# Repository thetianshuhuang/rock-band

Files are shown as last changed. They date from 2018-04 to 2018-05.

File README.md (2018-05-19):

# EE319K Final Project: Rock Band
Tianshu Huang and Quinn Buoy

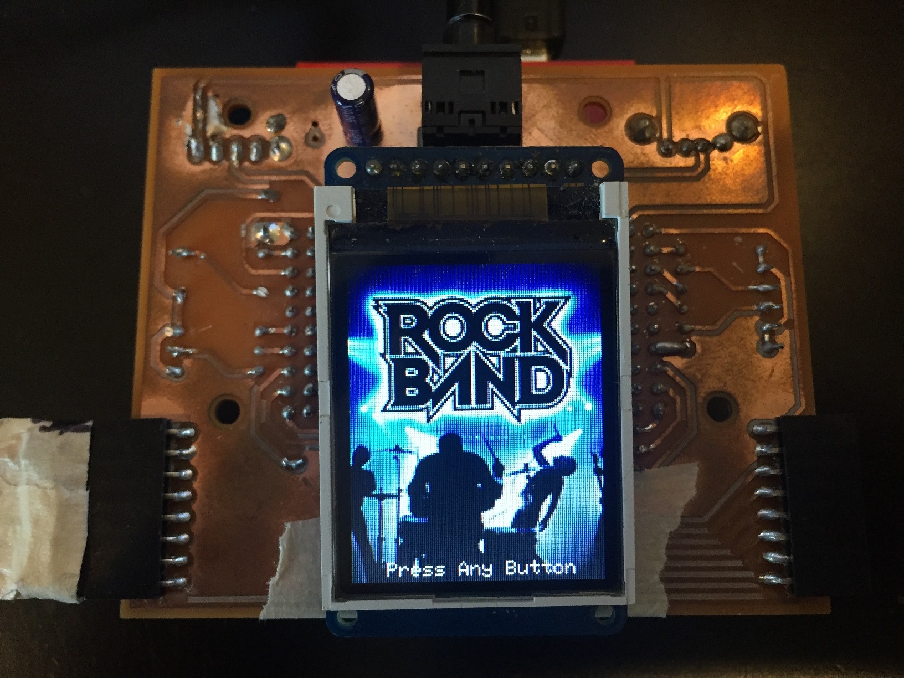
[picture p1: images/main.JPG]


## Game Overview
### Features
- 44.1kHz, 8 bit audio
- Audio and tracks via SD read
- inifinitely many songs supported, just by expanding the menu
- Full resolution (128x160) splash screens

### Dependencies
- tm4c123gh6p.h (tm4c hardware register definition file)
- PLL.h (TM4C PLL; used for 80mHz clock)
- FATFS; ST7735.h and diskio.h from Valvanoware (modified)

### Libraries and Modules
- Network: token network implementation, modified from Serial Token Ring
- Audio: SD read and DAC out; 8 bit x 44.1kHz (44.1kBps bitrate)
- Controller: Four digital and one analog, and derivative routines for the strummer
- Game: Core game control
- Display: SD drivers and display routines
- Menu: Generalized menu library using function pointers
- Graphics: Display routines for the guitar, splash screen, and misc utilities

### File Types
- Packed Image (.pi): packed 5-6-5 GBR 16-bit image, uncompressed, scanning starting from bottom left, across, then up
- Byte wave file (.bw): raw audio file, bit-depth of 8, 44.1kHz
- Rock Band Track (.rb): 16-bit array.
```
| R | Y | B | G | Reserved | Reserved | -- (10) Tick -- |
```
	- R, Y, B, G indicates whether each drum should be hit (1) at that note
or not (0).
	- Tick indicates the number of updates (441 updates/s or 100 audio ticks/update)
before the next note.

## Gameplay
Navigate the menus using the four buttons or by hitting the drums.

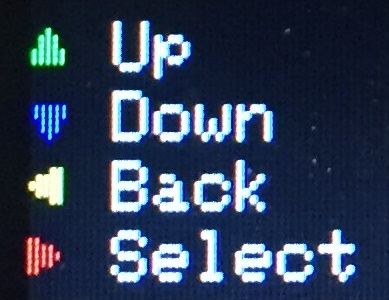
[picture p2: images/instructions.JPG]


At first, the Menu screen will have a black background. Navigate to 'select instrument', and choose the desired instrument. Then, the background will change to match the chosen instrument. Then, select 'Enable Full Mode' to disable the 2:30 time limit on song duration if desired.

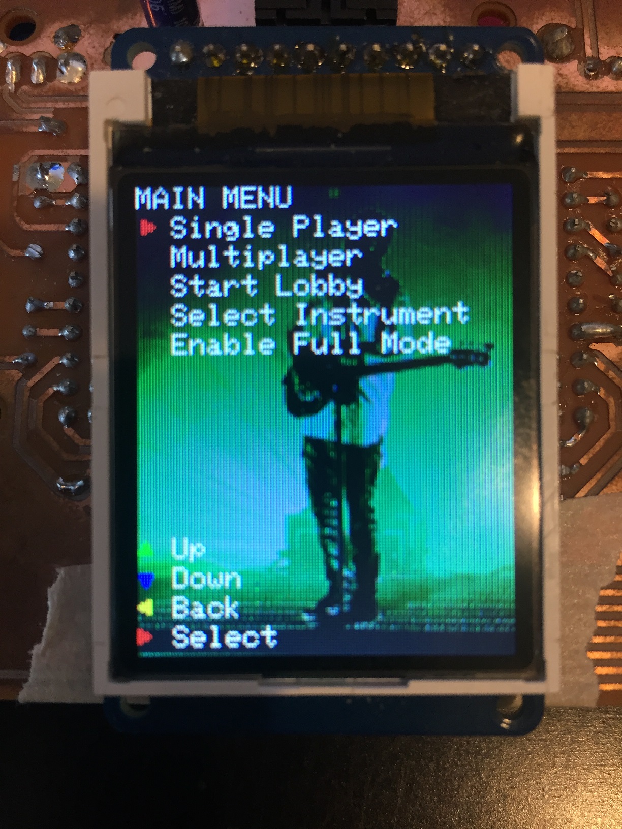
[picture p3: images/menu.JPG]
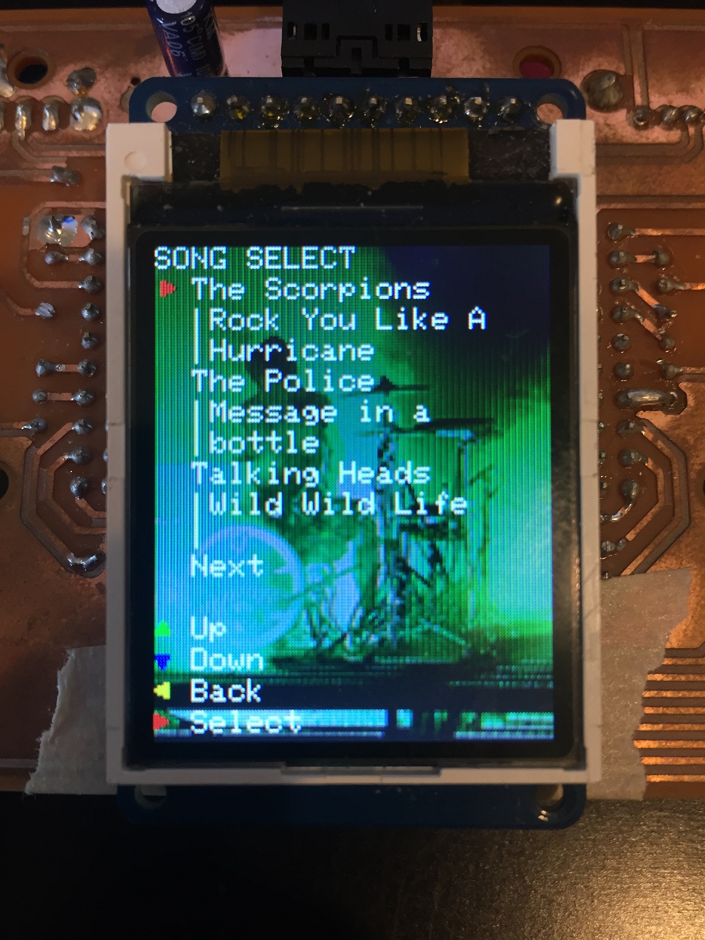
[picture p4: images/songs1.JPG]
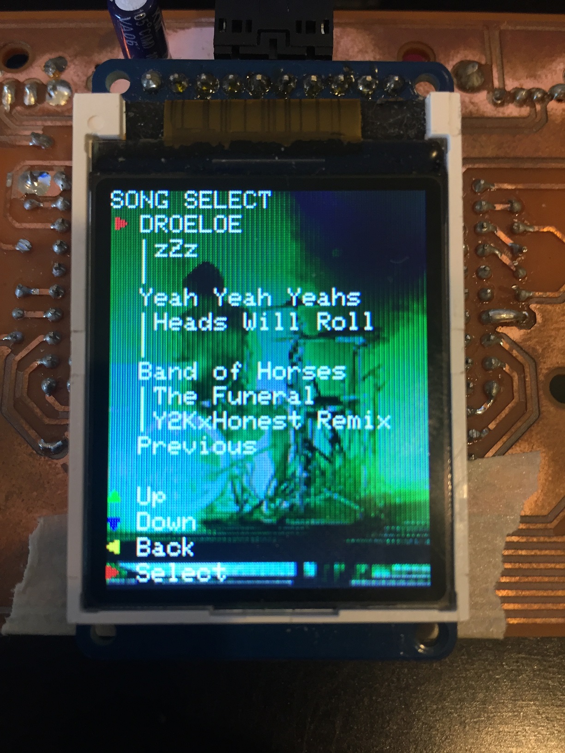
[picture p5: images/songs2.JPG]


All but one device should choose 'Join Lobby'. These devices will wait for the main ('Lobby Leader') device to choose a song, and join in.

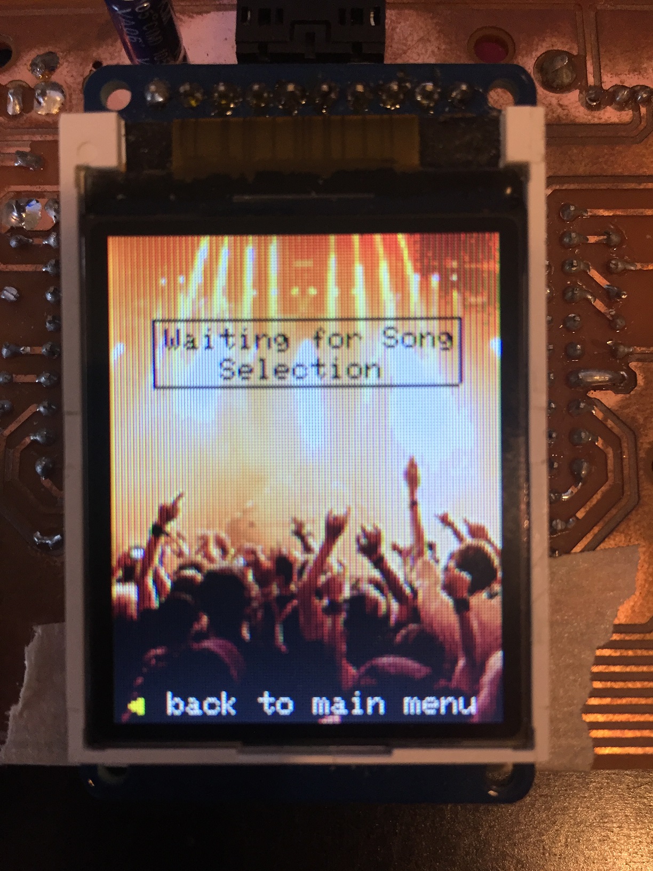
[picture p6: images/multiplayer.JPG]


All devices on the multiplayer "Waiting for Song Selection" screen will join the main device once a song is selected.
After a song is started, notes will scroll down the screen. Play notes by holding down the appropriate buttons and strumming (guitar/bass) or by hitting the drum pads. Hit notes will increase the score; missed notes will decrease the score. Once enough notes are hit, Star Power is enabled, turning the frets yellow and the notes white, and provides a score multiplier. Poor performance increases the difficulty of obtaining Star Power. The duration of Star Power increases on successful note hits, and decreases greatly on missed notes. 

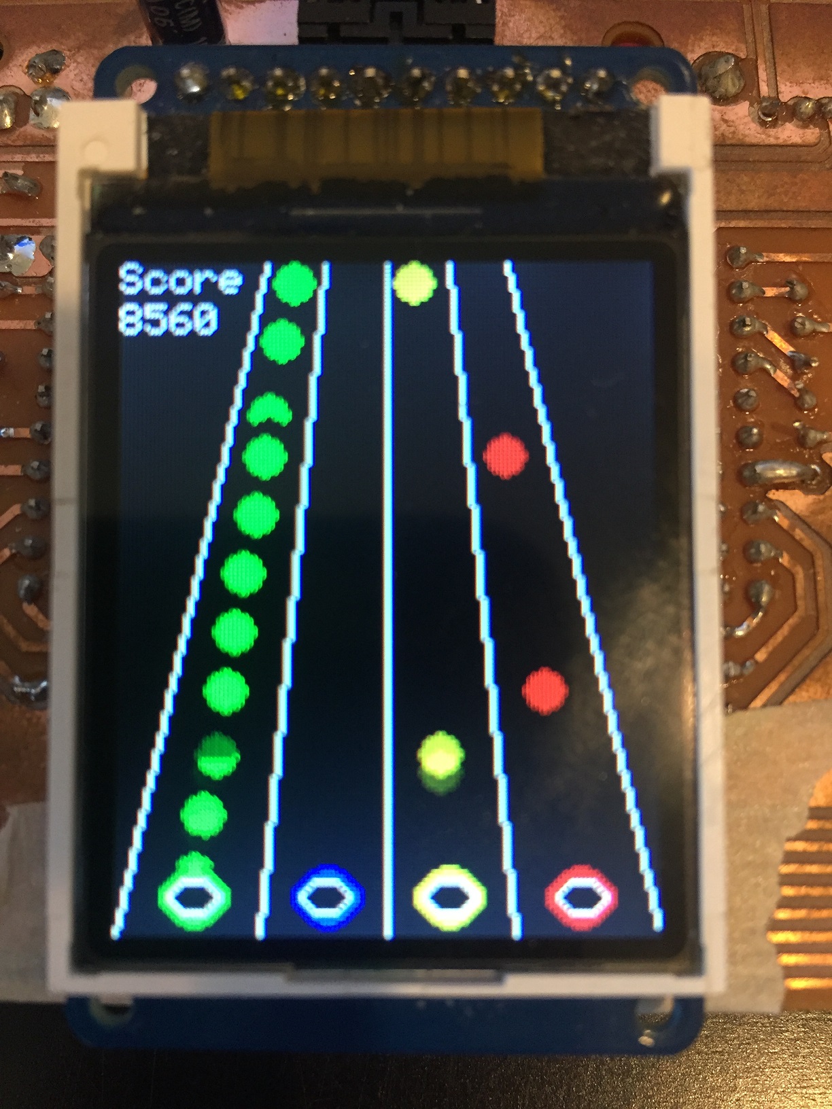
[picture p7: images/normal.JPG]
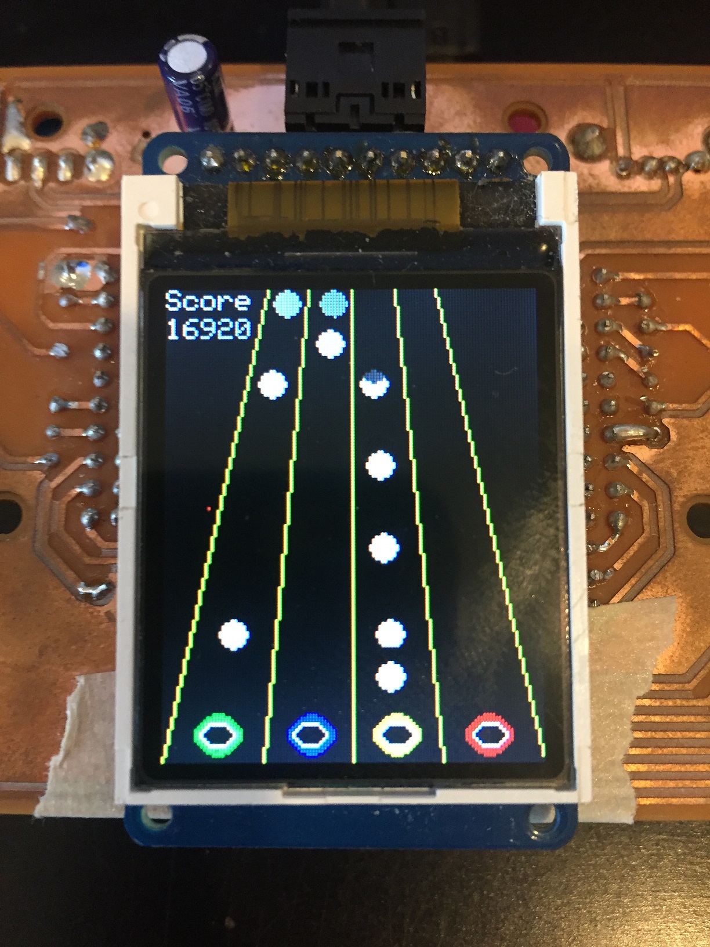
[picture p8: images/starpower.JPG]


## Setup instructions
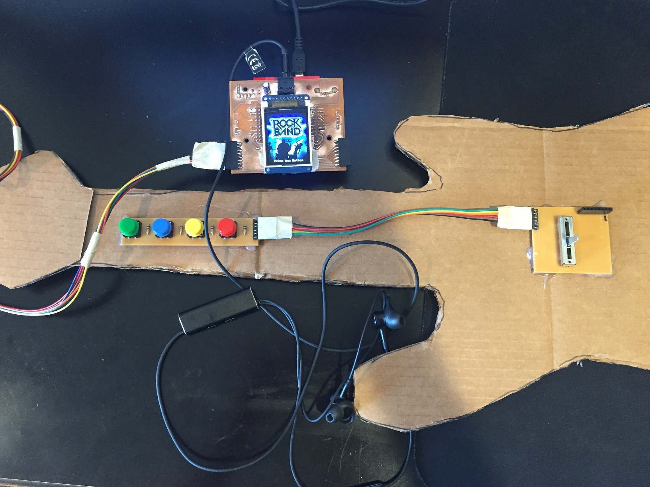
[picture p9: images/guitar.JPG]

1. Format the SD card as FAT32.

2. Copy the contents of 'resources' to the SD card.

3. Flash code to the TM4C.

4. Plug the TM4C and ST7735R into the main board and insert the SD card in the ST7735R's SD card slot

5. If playing with a guitar, use the 8 pin cable to connect one of the 8 pin connectors on the side of the main board to the 8 pin slot on the guitar. Ensure that the pin on the upper end of the main board (3.3v) is connected to the pin at the bottom of the guitar. Then, connect the male 6 pin connectors on the strummer board and button board. With both boards facing up, the 6 pin cable should be turned 180 degrees.

6. If playing with the drums, plug the 8 pin cable into the top 8 pin connector, with the 3.3v pin connected to the pin closest to the power LED. Then, plug each piezo sensor into the bottom 8 pin connector, with each piezo connected to two adjacent pins.

7. Connect the USB A port of each main board to the USB Micro B port of the next board. Note that the USB cable should not be plugged into either of the TM4C's USB ports. Connect the last board's USB A port to the USB Micro B port of the first board.

8. Connect a 5v source to one of the launchpads, either through the 5v pin or the TM4C's onboard USB port.

## Materials
### Main Client Board
- Main PCB
- Micro USB to USB A cable
- ST7735R
- Micro SD Card
- Male-to-male cable, 8 pin
### Guitar Controller
- Button board
- Strummer base board
- 6 Pin female to female ribbon cable
### Drum Controller
- Op Amp drum controller board
- 4 Piezo sensors

## PCBs
### Main Board
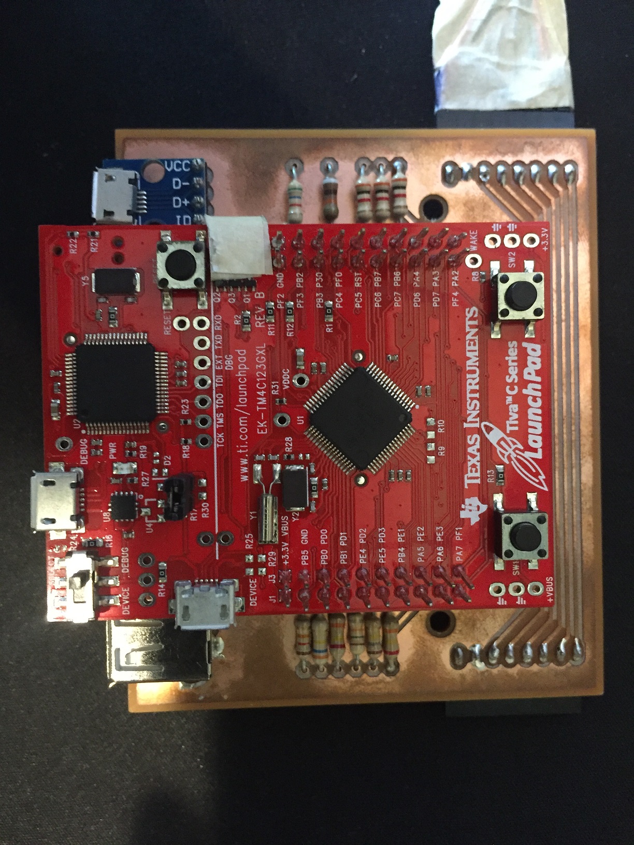
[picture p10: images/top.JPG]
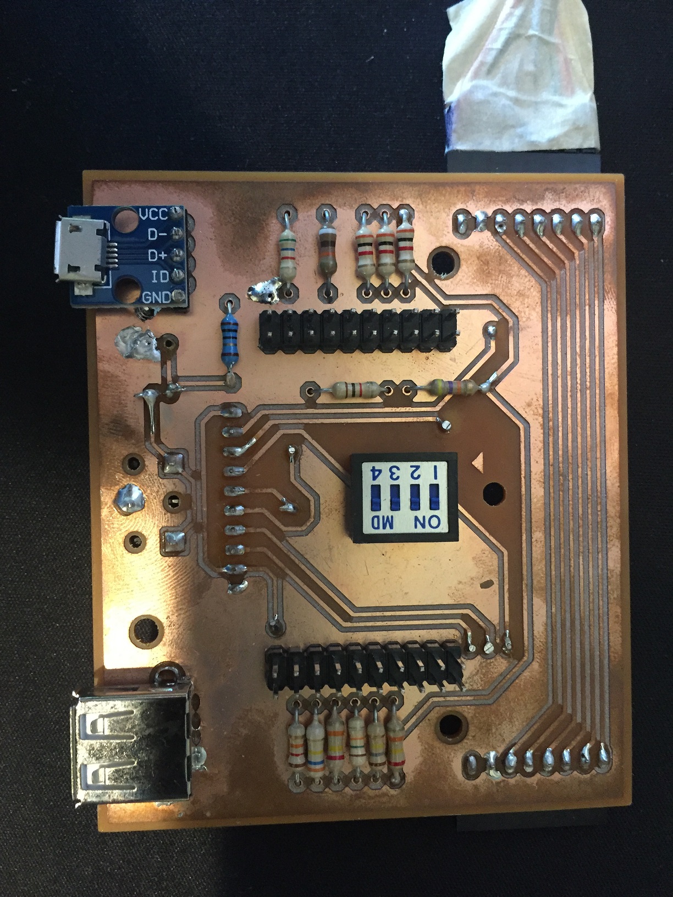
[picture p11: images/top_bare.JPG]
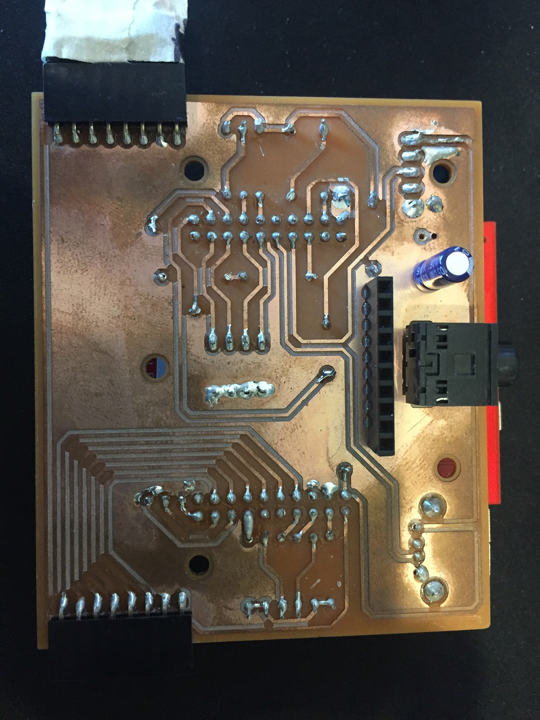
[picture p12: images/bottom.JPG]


- 1x Micro USB Breakout
- 1x USB A Port
- 1x 3.5mm Jack
- 1x 10&mu;f Capacitor
- 2x 1x8 Right angle Female Connector
- 1x 1x10 Female Connector
- 3x Switch
- Resistors: 1x 10&Omega;, 1x 1k&Omega;, 3x 3k&Omega;, 1x 5.1k&Omega;, 1x 12k&Omega;, 1x 16k&Omega;, 2x 24k&Omega;, 1x 47.1k&Omega;, 1x 91k&Omega;, 1x 180k&Omega;, 1x 360k&Omega;

### Strummer Board
- 1x 1x6 Right angle male connector
- 1x 1x8 Female header
- 1x Red LED
- 1x 220&Omega; Resistor
- 1x Slide Potentiometer

### Button Board
- 4x Buttons
- 4x 10k&Omega; Resistors

### Drums
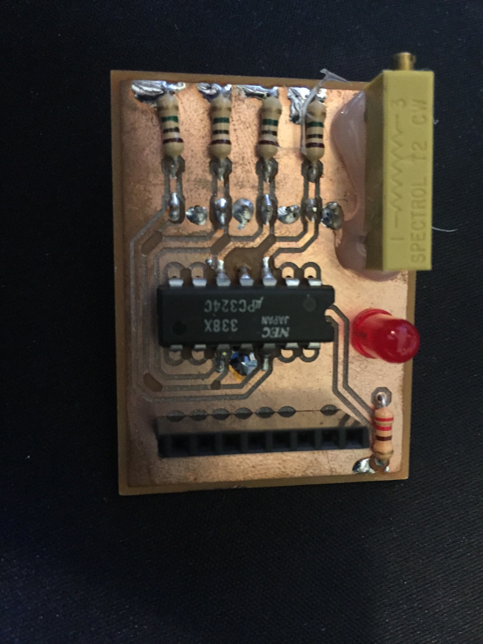
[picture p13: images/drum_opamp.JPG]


- 2x 1x8 Female Header
- 1x 20k (or similar) Cermet Potentiometer
- 1x PC324C Quad Op Amp or Equivalent
- 1x Red LED
- 1x 220&Omega; Resistor
- 4x 1M&Omega; Resistors

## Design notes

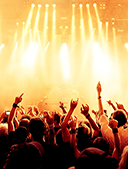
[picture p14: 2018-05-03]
source/graphics/sd_data/wait.bmp

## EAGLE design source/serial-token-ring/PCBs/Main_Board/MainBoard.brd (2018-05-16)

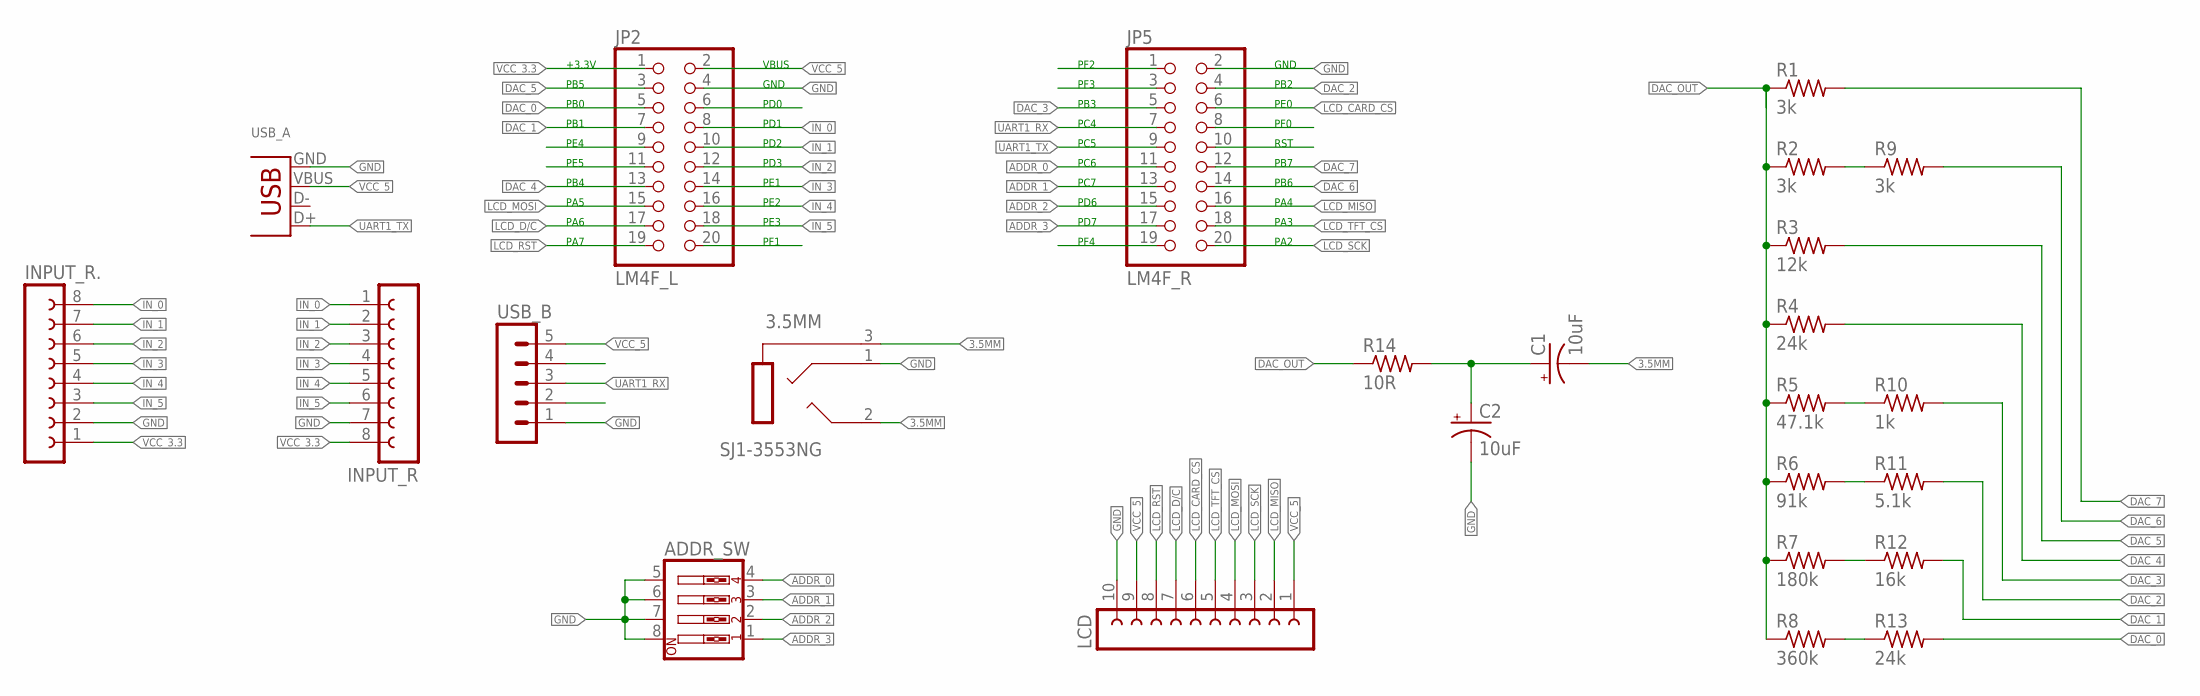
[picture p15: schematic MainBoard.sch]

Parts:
3.5MM: SJ1-3553NG
ADDR_SW: SW_DIP-4; EDG-04
C1, C2: 10uF; E2-4
INPUT_R, INPUT_R.: FE08W
JP2: LM4F_L; 2X10
JP5: LM4F_R; 2X10
LCD: FE10-1; FE10
R1, R2, R9: 3k; 0309/10
R3: 12k; 0309/10
R4, R13: 24k; 0309/10
R5: 47.1k; 0309/10
R6: 91k; 0309/10
R7: 180k; 0309/10
R8: 360k; 0309/10
R10: 1k; 0309/10
R11: 5.1k; 0309/10
R12: 16k; 0309/10
R14: 10R; 0309/10
USB_A: USB-A-H
USB_B: MA05-1

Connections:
3.5MM: 3.5MM.2 (TIP), 3.5MM.3 (SLEEVE), C1.-
ADDR_0: ADDR_SW.4, JP5.11
ADDR_1: ADDR_SW.3, JP5.13
ADDR_2: ADDR_SW.2, JP5.15
ADDR_3: ADDR_SW.1, JP5.17
DAC_0: JP2.5, R13.2
DAC_1: JP2.7, R12.2
DAC_2: JP5.4, R11.2
DAC_3: JP5.5, R10.2
DAC_4: JP2.13, R4.2
DAC_5: JP2.3, R3.2
DAC_6: JP5.14, R9.2
DAC_7: JP5.12, R1.2
DAC_OUT: R1.1, R2.1, R3.1, R4.1, R5.1, R6.1, R7.1, R8.1, R14.1
GND: 3.5MM.1 (RING), ADDR_SW.5, ADDR_SW.6, ADDR_SW.7, ADDR_SW.8, C2.-, INPUT_R.7, INPUT_R..2, JP2.4, JP5.2, LCD.10, USB_A.GND, USB_B.1
IN_0: INPUT_R.1, INPUT_R..8, JP2.8
IN_1: INPUT_R.2, INPUT_R..7, JP2.10
IN_2: INPUT_R.3, INPUT_R..6, JP2.12
IN_3: INPUT_R.4, INPUT_R..5, JP2.14
IN_4: INPUT_R.5, INPUT_R..4, JP2.16
IN_5: INPUT_R.6, INPUT_R..3, JP2.18
LCD_CARD_CS: JP5.6, LCD.6
LCD_D/C: JP2.17, LCD.7
LCD_MISO: JP5.16, LCD.2
LCD_MOSI: JP2.15, LCD.4
LCD_RST: JP2.19, LCD.8
LCD_SCK: JP5.20, LCD.3
LCD_TFT_CS: JP5.18, LCD.5
unnamed: C1.+, C2.+, R14.2
unnamed: R7.2, R12.1
unnamed: R8.2, R13.1
unnamed: R2.2, R9.1
unnamed: R5.2, R10.1
unnamed: R6.2, R11.1
PD0: JP2.6
PE4: JP2.9
PE5: JP2.11
PF0: JP5.8
PF1: JP2.20
PF2: JP5.1
PF3: JP5.3
PF4: JP5.19
RST: JP5.10
UART1_RX: JP5.7, USB_B.3
UART1_TX: JP5.9, USB_A.D+
VCC_3.3: INPUT_R.8, INPUT_R..1, JP2.1
VCC_5: JP2.2, LCD.1, LCD.9, USB_A.VBUS, USB_B.5

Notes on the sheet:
+3.3V
PB5
PB0
PB1
PE4
PE5
PB4
PA5
PA6
PA7
VBUS
GND
PD0
PD1
PD2
PD3
PE1
PE2
PE3
PF1
PF2
PF3
PB3
PC4
PC5
PC6
PC7
PF4
PB2
PE0
PF0
RST
PB7
PB6
PA4
PA3
PA2
PD6
PD7

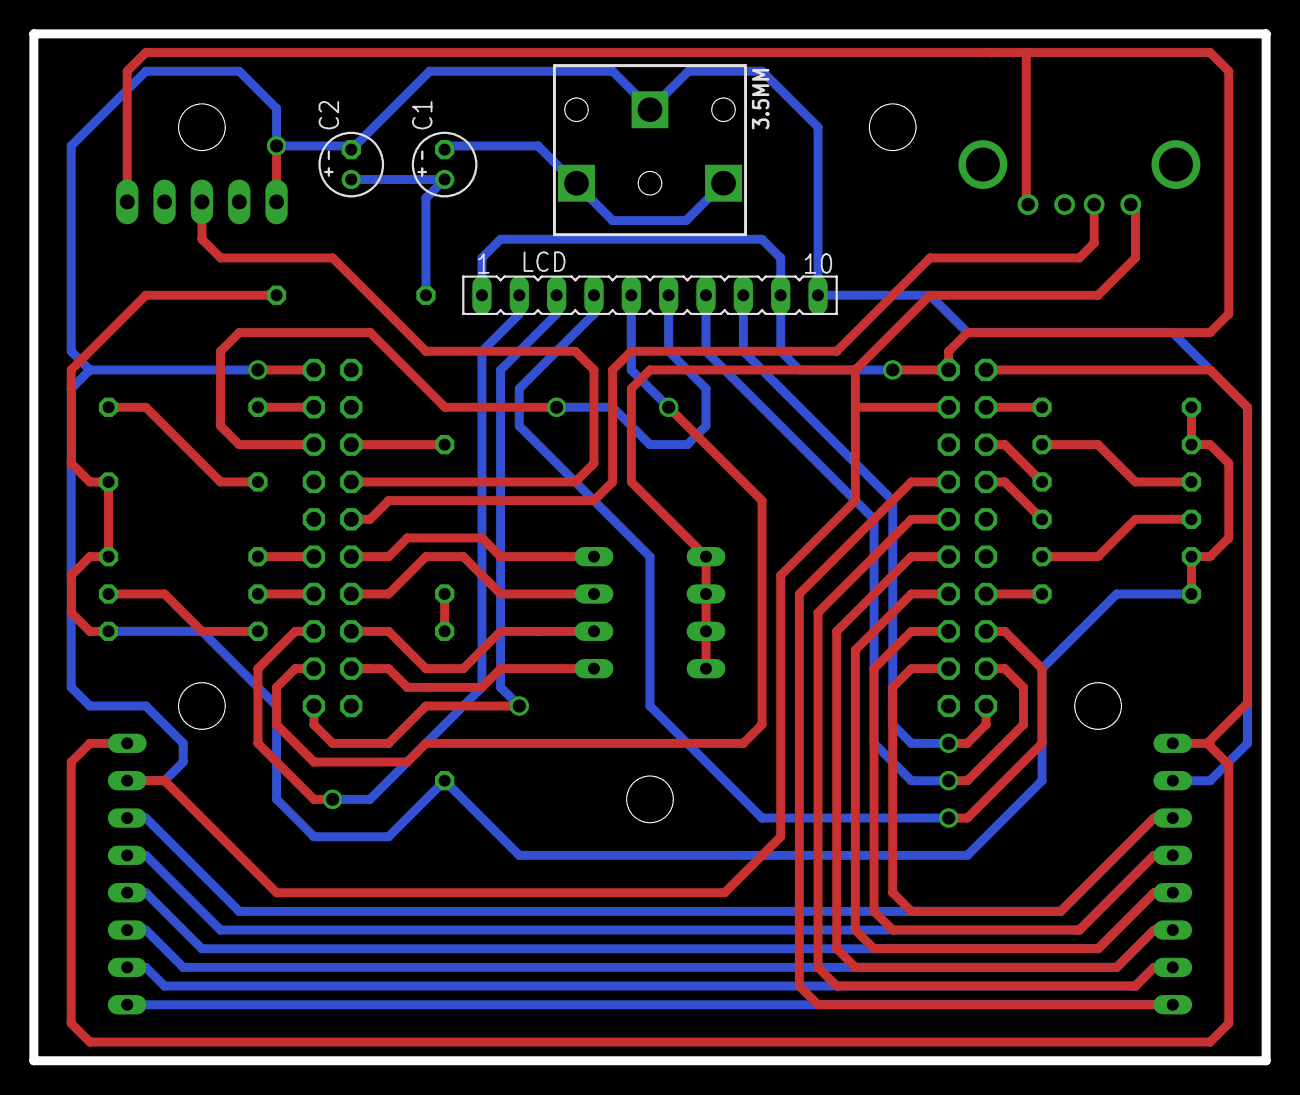
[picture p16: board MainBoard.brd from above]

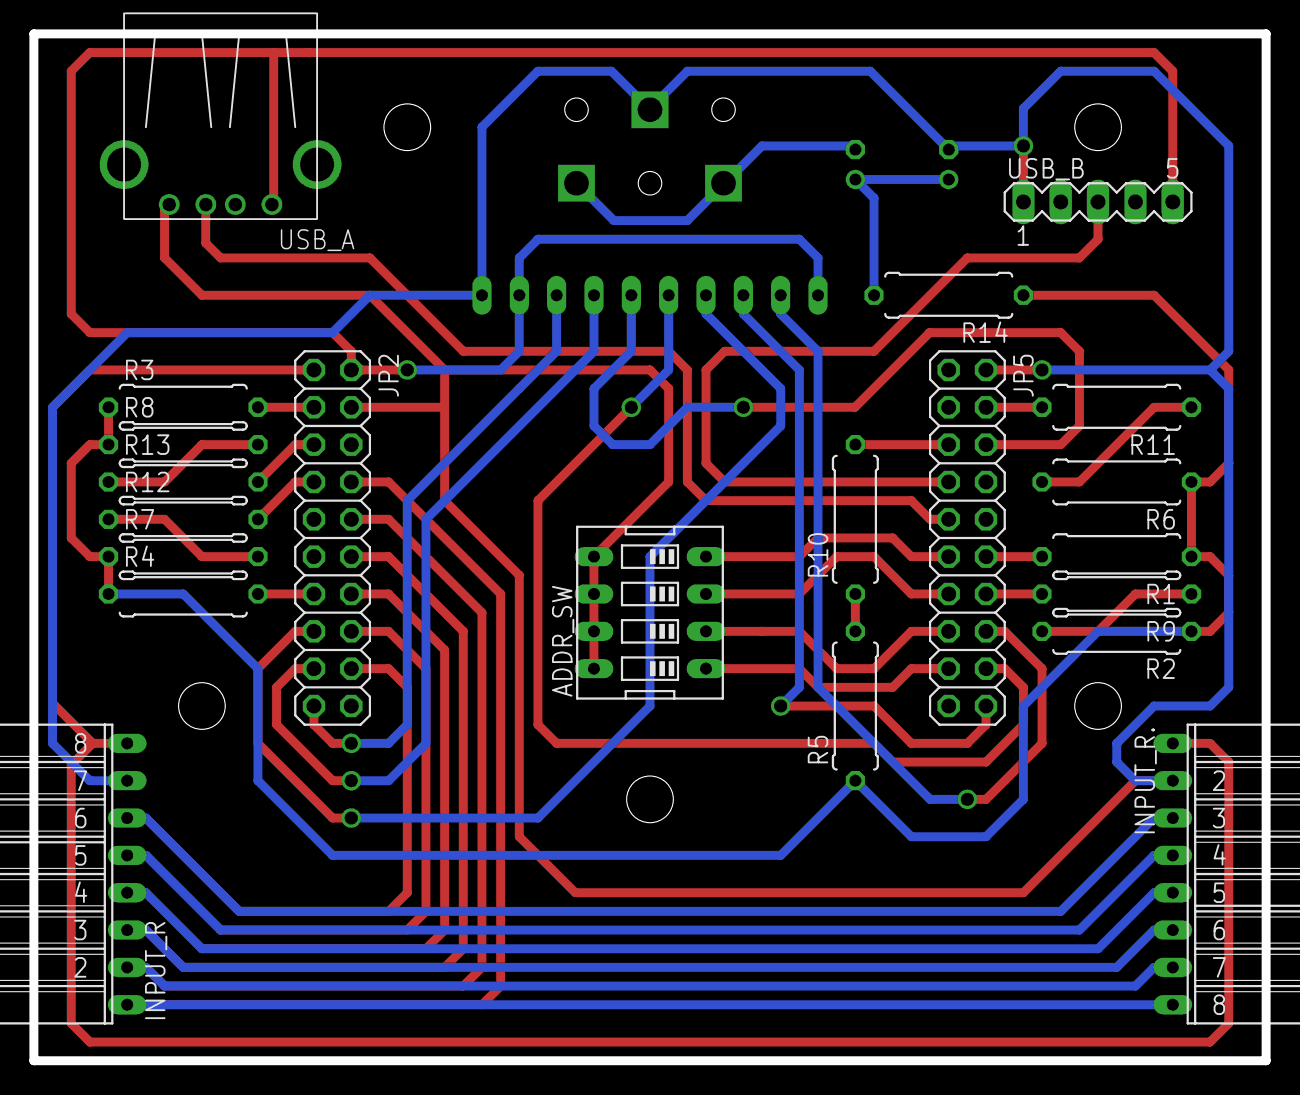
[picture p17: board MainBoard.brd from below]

Board: 2 copper layers, 83.8 x 69.8 mm, 25 parts (21 on the bottom side), 38 nets.

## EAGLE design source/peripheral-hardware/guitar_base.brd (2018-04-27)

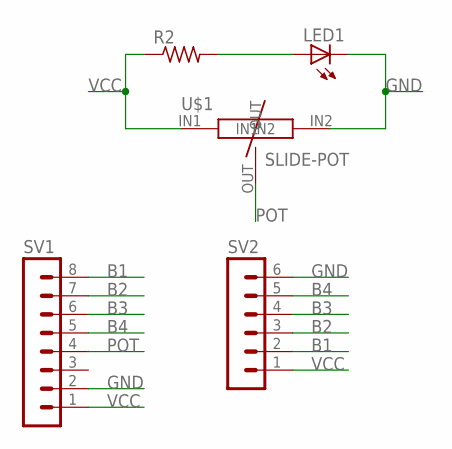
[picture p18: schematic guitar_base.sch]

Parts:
LED1: LED5MM
R2: R-US_0207/7; 0207/7
SV1: MA08-1
SV2: MA06-1
U$1: SLIDE-POT

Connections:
B1: SV1.8, SV2.2
B2: SV1.7, SV2.3
B3: SV1.6, SV2.4
B4: SV1.5, SV2.5
GND: LED1.K (C), SV1.2, SV2.6, U$1.IN2
unnamed: LED1.A, R2.2
POT: SV1.4, U$1.OUT
VCC: R2.1, SV1.1, SV2.1, U$1.IN1

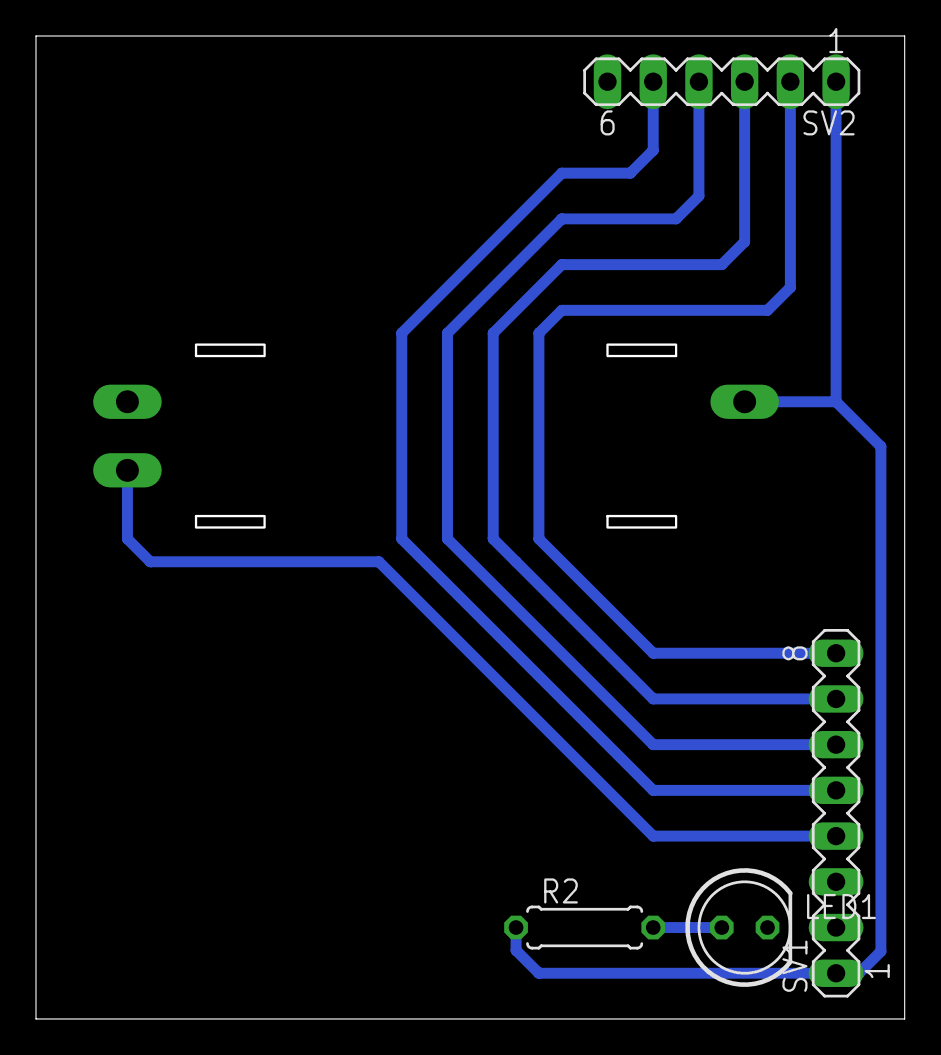
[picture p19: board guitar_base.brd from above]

Board: 2 copper layers, 48.3 x 54.6 mm, 5 parts (0 on the bottom side), 8 nets.

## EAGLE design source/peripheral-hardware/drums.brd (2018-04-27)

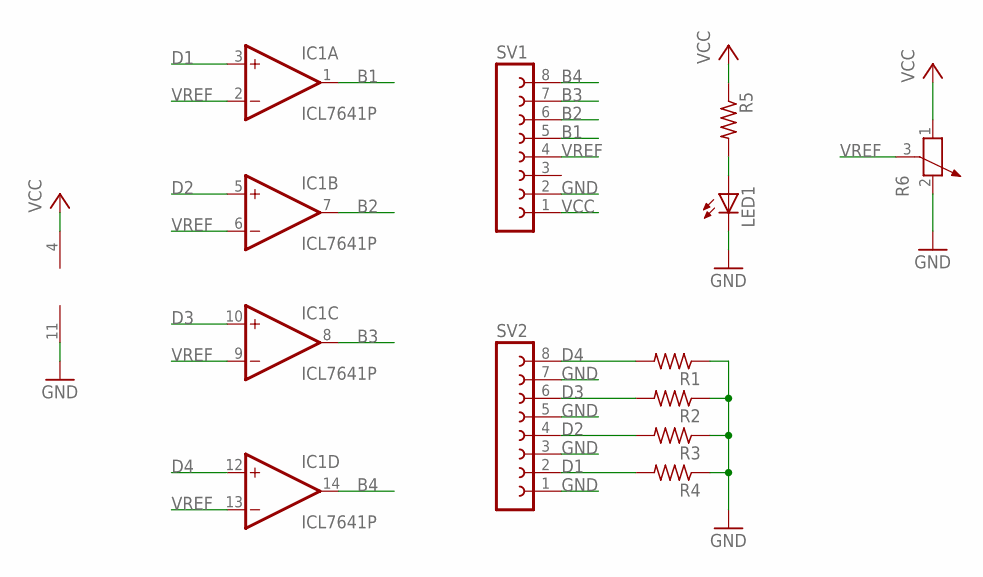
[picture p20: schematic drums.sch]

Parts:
IC1: ICL7641P; DIL14
LED1: LED5MM
R1, R2, R3, R4, R5: R-US_0207/7; 0207/7
R6: POTENTIOMETER_PT_SPIN; PT-SPIN
SV1, SV2: FE08-1; FE08

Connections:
B1: IC1.1 (OUT), SV1.5
B2: IC1.7 (OUT), SV1.6
B3: IC1.8 (OUT), SV1.7
B4: IC1.14 (OUT), SV1.8
D1: IC1.3 (+IN), R4.2, SV2.2
D2: IC1.5 (+IN), R3.2, SV2.4
D3: IC1.10 (+IN), R2.2, SV2.6
D4: IC1.12 (+IN), R1.2, SV2.8
GND: IC1.11 (V-), LED1.K (C), R1.1, R2.1, R3.1, R4.1, R6.2, SV1.2, SV2.1, SV2.3, SV2.5, SV2.7
unnamed: LED1.A, R5.2
VCC: IC1.4 (V+), R5.1, R6.1, SV1.1
VREF: IC1.2 (-IN), IC1.6 (-IN), IC1.9 (-IN), IC1.13 (-IN), R6.3, SV1.4

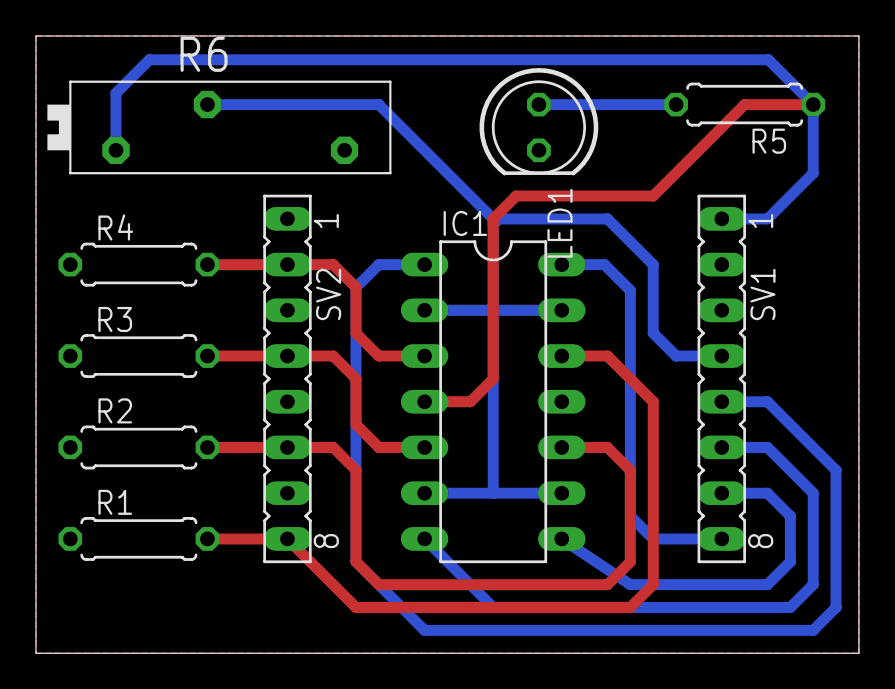
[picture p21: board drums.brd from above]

Board: 2 copper layers, 45.7 x 34.3 mm, 10 parts (0 on the bottom side), 12 nets.

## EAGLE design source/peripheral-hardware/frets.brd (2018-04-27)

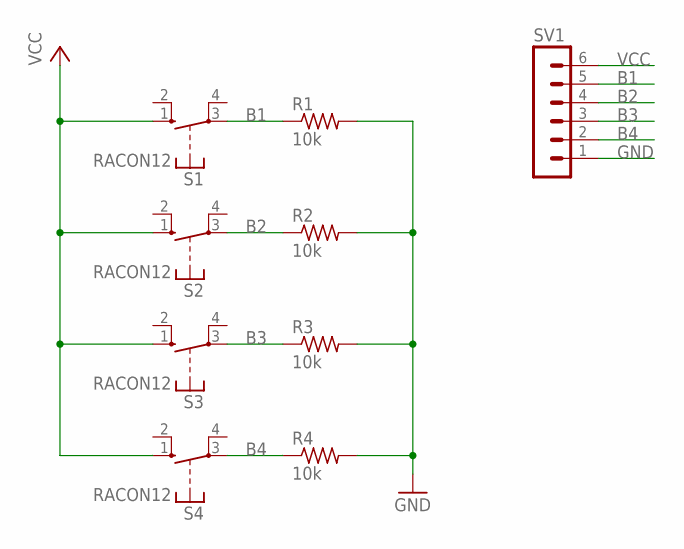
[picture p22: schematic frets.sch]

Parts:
R1, R2, R3, R4: 10k; 0207/7
S1, S2, S3, S4: RACON12
SV1: MA06-1

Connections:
B1: R1.1, S1.3, SV1.5
B2: R2.1, S2.3, SV1.4
B3: R3.1, S3.3, SV1.3
B4: R4.1, S4.3, SV1.2
GND: R1.2, R2.2, R3.2, R4.2, SV1.1
VCC: S1.1 (S), S2.1 (S), S3.1 (S), S4.1 (S), SV1.6

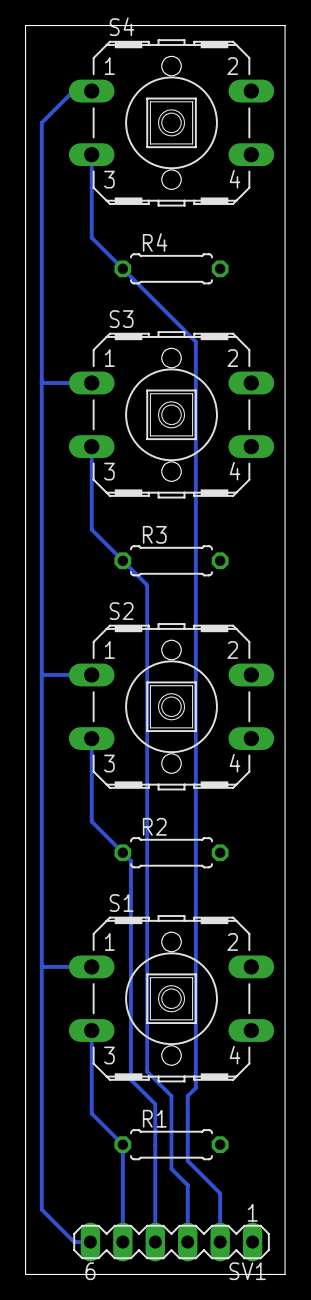
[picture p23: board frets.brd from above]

Board: 2 copper layers, 20.3 x 97.8 mm, 9 parts (0 on the bottom side), 6 nets.

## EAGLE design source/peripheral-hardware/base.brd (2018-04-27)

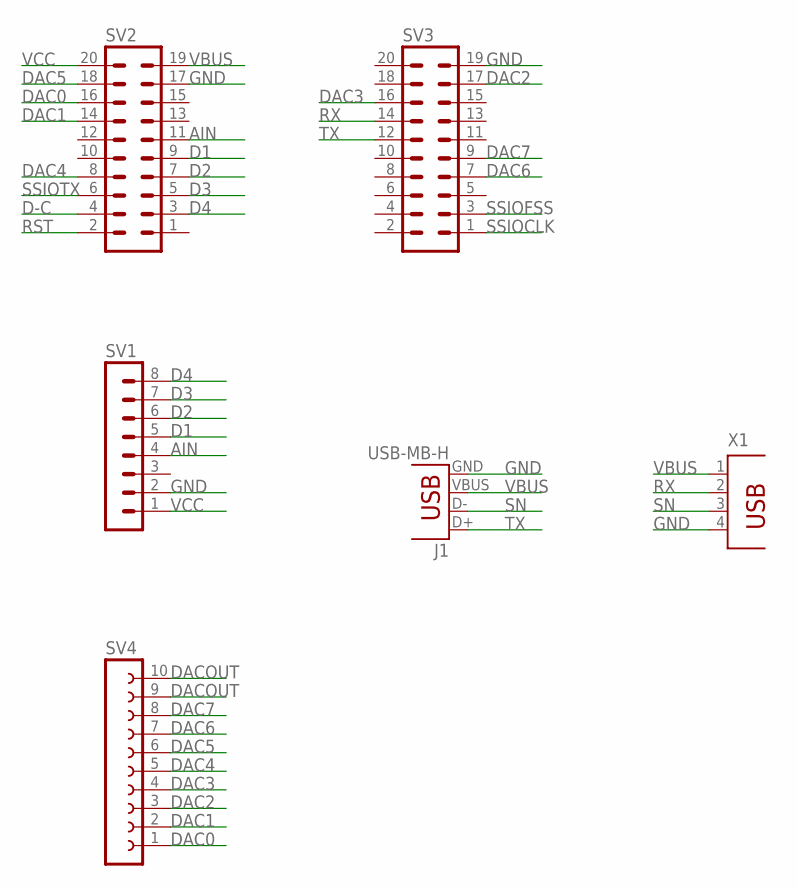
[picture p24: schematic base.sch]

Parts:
J1: USB-MB-H
SV1: MA08-1
SV2, SV3: MA10-2
SV4: FE10-1; FE10
X1: PN87520

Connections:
AIN: SV1.4, SV2.11
D1: SV1.5, SV2.9
D2: SV1.6, SV2.7
D3: SV1.7, SV2.5
D4: SV1.8, SV2.3
D-C: SV2.4
DAC0: SV2.16, SV4.1
DAC1: SV2.14, SV4.2
DAC2: SV3.17, SV4.3
DAC3: SV3.16, SV4.4
DAC4: SV2.8, SV4.5
DAC5: SV2.18, SV4.6
DAC6: SV3.7, SV4.7
DAC7: SV3.9, SV4.8
DACOUT: SV4.9, SV4.10
GND: J1.GND, SV1.2, SV2.17, SV3.19, X1.4
RST: SV2.2
RX: SV3.14, X1.2
SN: J1.D-, X1.3
SSIOCLK: SV3.1
SSIOFSS: SV3.3
SSIOTX: SV2.6
TX: J1.D+, SV3.12
VBUS: J1.VBUS, SV2.19, X1.1
VCC: SV1.1, SV2.20

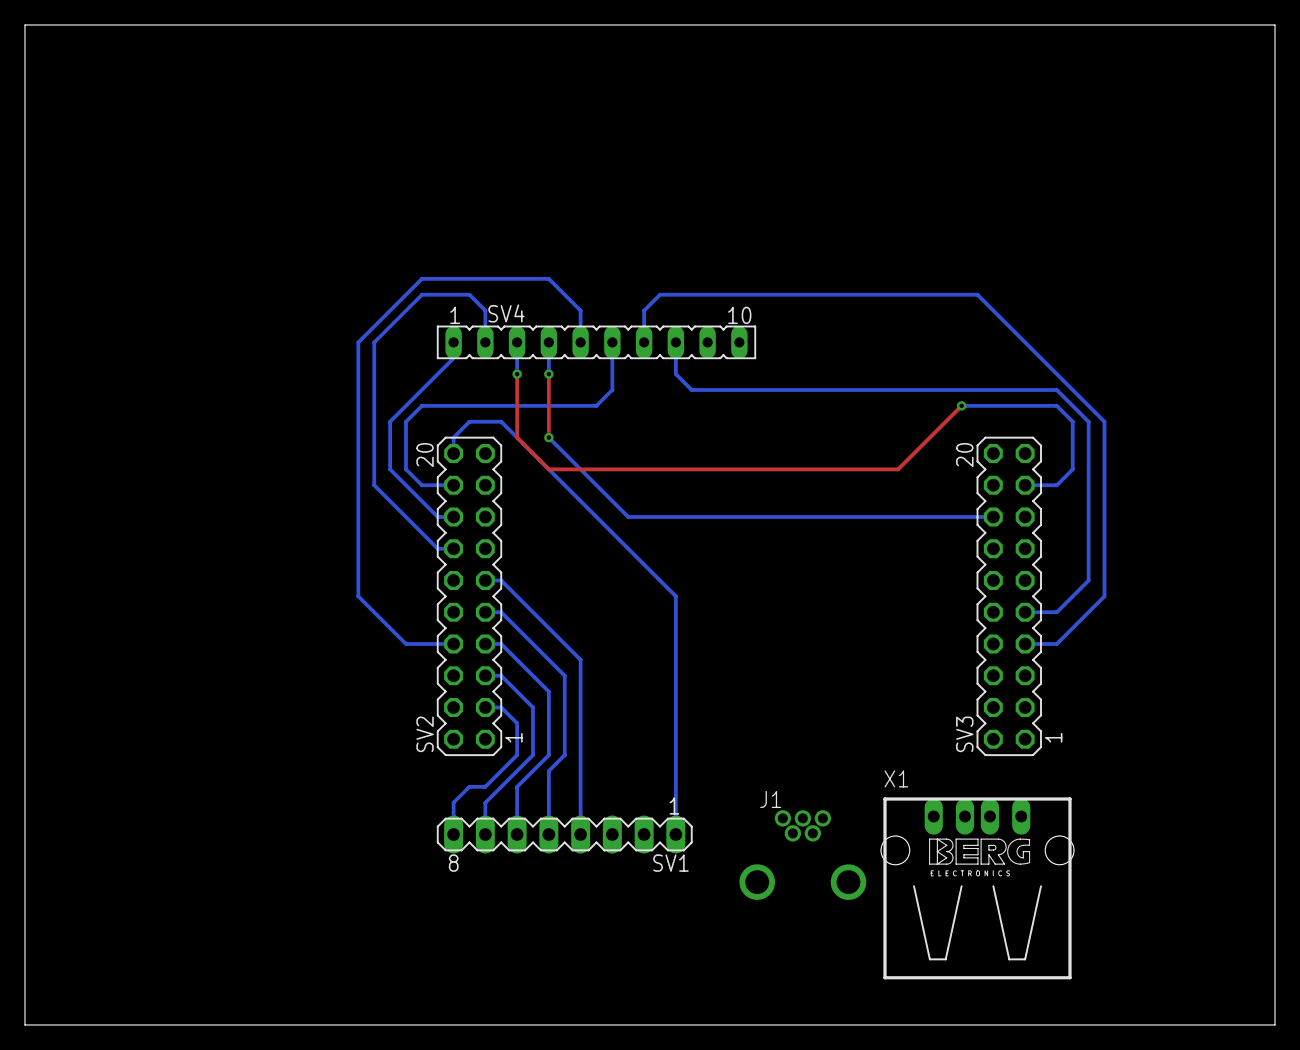
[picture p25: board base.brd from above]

Board: 2 copper layers, 100.0 x 80.0 mm, 6 parts (0 on the bottom side), 20 nets.

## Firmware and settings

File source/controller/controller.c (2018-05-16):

/*
 * controller.c
 *
 * I/O interfacing for the game controller
 * Analog: PE2
 * Digital: PE1, PD1-D3
 * 
 * Potentiometer on Drum Controller:
 *  - Clockwise -> Less Sensitive
 *  - Approximate value: 0.75v
 */


#include "controller.h"
#include "../tm4c123gh6pm.h"


#define ADC_SAMPLE_RATE 200000
long StartCritical (void);
void EndCritical(long sr);

// ----------waitFourNops----------
// Helper function that just NOPs four times
void waitFourNops() {
    __asm{NOP};
    __asm{NOP};
    __asm{NOP};
    __asm{NOP};
}

// ----------controllerInit----------
// Initialize controller
void controllerInit(void) {
    // Turn on clocks for port D, E
    SYSCTL_RCGCGPIO_R |= 0x19;
    waitFourNops();
    // PE1, PD1-D3 digital
    GPIO_PORTD_AMSEL_R &= ~0x0E;
    GPIO_PORTD_DIR_R &= ~0x0E;
    GPIO_PORTD_AFSEL_R &= ~0x0E;
    GPIO_PORTD_DEN_R |= 0x0E;
    
    GPIO_PORTE_AMSEL_R &= ~0x02;
    GPIO_PORTE_DIR_R &= ~0x02;
    GPIO_PORTE_AFSEL_R &= ~0x02;
    GPIO_PORTE_DEN_R |= 0x02;
    
    // PE2 analog
    GPIO_PORTE_DIR_R |= 0x04;
    GPIO_PORTE_AFSEL_R |= 0x04;
    GPIO_PORTE_DEN_R &= ~0x04;
    GPIO_PORTE_AMSEL_R |= 0x04;
    
    // Configure ADC0
    SYSCTL_RCGCADC_R |= 0x01;   // Activate ADC0
    waitFourNops();
    waitFourNops();
    ADC0_PC_R = 0x07;           // 1M (80 clocks) conversion speed
    ADC0_SSPRI_R = 0x0123;      // set priorities
    ADC0_ACTSS_R &= ~0x08;      // disable sample sequencer 3
    ADC0_EMUX_R &= ~0xF000;     // seq3 is set to software trigger
    ADC0_SSMUX3_R &= ~0x0F;     // Clear SS3 field
    ADC0_SSMUX3_R = 0x01;       // set channel to Ain1 (PE2)
    ADC0_SSCTL3_R = 0x06;
    ADC0_SAC_R = 0x03;
    ADC0_IM_R &= ~0x08;         // disable ss3 interrupts
    ADC0_ACTSS_R |= 0x08;       // enable ss3
    
    // Configure timer0
    long sr = StartCritical();
    SYSCTL_RCGCTIMER_R |= 0x01;
    TIMER0_CTL_R = 0x00000000;          // Disable timer
    TIMER0_CFG_R = 0x00000000;          // 32-bit mode
    TIMER0_TAMR_R = 0x000000002;        // Periodic mode
    TIMER0_TAILR_R = ADC_SAMPLE_RATE;   // Set reload value
    TIMER0_TAPR_R = 0;                  // Use bus clock
    TIMER0_ICR_R = 0x000000001;         // Clear timeout flag
    TIMER0_IMR_R = 0x000000001;         // Enable interrupt
    NVIC_PRI4_R = (NVIC_PRI4_R & 0x00FFFFFF) | 0x80000000;
                                        // Set priority to the same as the main timer
    NVIC_EN0_R = 1<<19;                 // Enable IRQ 19 in NVIC
    EndCritical(sr);

    // PF0, PF4 inputs
    SYSCTL_RCGCGPIO_R |= 0x20;
    waitFourNops();
    GPIO_PORTF_DIR_R &= ~0x11;
    GPIO_PORTF_AFSEL_R &= ~0x11; 
    GPIO_PORTF_DEN_R |= 0x11;
    GPIO_PORTF_AMSEL_R &= ~0x11;
}


// Analog mailbox
uint16_t adcMailbox;
// ----------sampleAdc--------
// Take ADC sample and store to mailbox
void sampleAdc(void) {
    // Start sample
    ADC0_PSSI_R = 0x08;
    // Wait for conversion (~80 clocks)
    while((ADC0_RIS_R & 0x08) == 0){};
    // Set mailbox
    adcMailbox = ADC0_SSFIFO3_R & 0xFFF;
    // Clear sample complete flag
    ADC0_ISC_R = 0x08;
}


// ----------checkPause--------
// Check whether the game should be paused
// Returns:
//      1 for pause; 0 if no pause
uint8_t checkPause(void) {
    if((GPIO_PORTF_DATA_R & 0x11) != 0) {
        return(1);
    }
    return(0);
}


// ----------controllerRead----------
// Read the controller state
// Returns:
//      uint16_t: packed controller state
//          | button1 | button2 | button3 | button4| --strummer (12 bit) --|
uint16_t controllerRead(void) {

    return(
        ((GPIO_PORTD_DATA_R & 0x0E) << 11) |
        ((GPIO_PORTE_DATA_R & 0x02) << 14) |
        adcMailbox
    );
}

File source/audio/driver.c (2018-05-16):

/*
 * driver.c
 *
 * Audio driver
 * Plays raw hex-string audio files from an SD card
 */

#include "dac.h"
#include "driver.h"
#include "../display/ff.h"
#include "../display/diskio.h"
#include "fifo.h"
#include "../tm4c123gh6pm.h"


// Set audio period
#define AUDIO_PERIOD 0x716;
#define DIVIDER 1;


// Status codes from the SD library
FRESULT mountStatus, openStatus, readStatus;
// FATFS object
static FATFS sdFileSystem;
// not sure what this is
FIL handle;
// not sure what this does either
UINT successfulreads;
// Current index
uint32_t *currentIndex;
// Audio buffer
FIFO_QUEUE audioQueue;


// ----------audioInit----------
// Initialize audio driver
void audioInit(void) {
    // Initialize DAC
    DACInit();
}


// ----------startSong----------
// Start a song from the SD card
// Parameters:
//      char* songName: name of file to open
//      uint32_t* songCounter: pointer to current song index
uint32_t silence;
void startSong(const char* songName, uint32_t* songCounter) {

    // Debug heartbeat init
    SYSCTL_RCGCGPIO_R |= 0x20;
    __asm{NOP};
    __asm{NOP};
    GPIO_PORTF_DEN_R |= 0x0C;
    GPIO_PORTF_DIR_R |= 0x0C;
    GPIO_PORTF_AFSEL_R &= ~0x0C;
    GPIO_PORTF_AMSEL_R &= ~0x0C;
    
    // Initialize SD card filesystem
    do {
        mountStatus = f_mount(&sdFileSystem, "", 0);
    } while(mountStatus != 0);

    // Open song and load the first sector
    do {
        openStatus = f_open(&handle, songName, FA_READ);
    } while(openStatus != 0);
    fifoInit(&audioQueue);
    while(audioQueue.size < 18000) {
        readSector();
    }

    // Set silence at the beginning of the song
    silence = 114000;
    // Link current index
    currentIndex = songCounter;
    
    // Set up SysTick with priority 0, clock, and interrupts
    NVIC_ST_CTRL_R = 0;
    NVIC_ST_RELOAD_R = AUDIO_PERIOD;
    NVIC_ST_CURRENT_R = 0;
    NVIC_SYS_PRI3_R = (NVIC_SYS_PRI3_R & 0X00FFFFFF) | 0x00000000;
    NVIC_ST_CTRL_R = 0x0007;
    // Start timer0 (ADC and SD)
    TIMER0_CTL_R = 0x00000001;
}


// ----------endSong----------
// End the current song
void endSong(void) {
    // Disable interrupts
    NVIC_ST_CTRL_R = 0;
    TIMER0_CTL_R = 0x00000000;
    // Close file
    openStatus = f_close(&handle);
}


// ----------readSector----------
// Read at most one sector from the SD card into the audio queue
void readSector(void) {
    uint8_t readByte;
    // Read until audioQueue is full, or at most two sectors, unless the queue is almost empty
    for(uint16_t i = 0; ((i < 1024) || audioQueue.size < 5000) && (audioQueue.size < 18000); i++) {
        readStatus = f_read(&handle, &readByte, 1, &successfulreads);
        if(readStatus == 0) {
            fifoPut(&audioQueue, readByte);
        }
    }
}


// ----------updateSong----------
// Execute a song update
void updateSong(void) {
    char data;
    if(silence == 0) {
        fifoGet(&audioQueue, &data);
        DACOut(data);
        *currentIndex -= DIVIDER;
    }
    else {
        silence --;
    }
}

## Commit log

2018-04-27 Added hardware folder
    [base.brd, base.sch, drums.brd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]
2018-04-28 More core framework
2018-04-29 Network driver setup
2018-04-29 Network forwarding implemented; input bugs related to mispelled register names fixed
    [controller.c, uart.c]
2018-04-29 Added thread locking to the network driver
2018-04-29 fixed wrong function definition
    [uart.c]
2018-04-29 Reorganized, changed thread synchronization to disable interrupts
2018-04-29 it compiles but timer5handler might break
2018-04-29 fixed sdcard cs defs
    [controller.c, diskio.c, main.c]
2018-04-29 fixed adc init
2018-04-29 fixed port D init
    [controller.c]
2018-04-30 Rewrote audio driver
2018-04-30 more audio period fixes
    [driver.c, main.c]
2018-04-30 One thing i missed in the previous merge
    [ST7735.c]
2018-04-30 Fixed encoding; audio fully working
    [driver.c, main.c]
2018-04-30 Fixed bug in ST7735.c where SetTextColor was ignored by OutChar
    [ST7735.c, controller.c, core.c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]
2018-04-30 Rencoded songs to fix truncation and overflow (mostly)
    [main.c]
2018-04-30 Added another song; small bugfixes to eliminate static-causing errors
    [core.c, driver.c, main.c]
2018-05-01 2 buttons work
2018-05-01 Revert "Committed main"
    This reverts commit 9c6da3cffdbf126f4f6c31b7696b545273a920fe.
    [main.c]
2018-05-01 Revert "2 buttons work"
    This reverts commit d61660353dbaf35d227f04d3ec5020367a01f830.
    [main.c]
2018-05-01 Revert "Revert "2 buttons work""
    This reverts commit 26ddff079f539dd616473a53337aec290bd5eee3.
    [main.c]
2018-05-01 Fixed major SD card reading bug
    [ST7735.c, core.c, diskio.c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]
2018-05-01 Added pause button
2018-05-02 Added framework for score tracking
2018-05-02 score framework down but not working
    [core.c]
2018-05-02 need to debug adc
2018-05-03 Changed SD failure mode from delayed update to dropped updates
    [driver.c]
2018-05-03 Added star power framework; upped graphics steps from 19 to 32
2018-05-03 Added menu framework, more spash screens
2018-05-04 added i2c files
2018-05-04 Changes (bugfixes) from last night
    [core.c, main.c]
2018-05-04 Fixed menu bug introduced by refactoring
    [core.c, driver.c]
2018-05-16 Reorganized files and added images
    [MainBoard.brd, MainBoard.sch, base.brd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]
2018-05-16 Switched to HTML images
2018-05-16 Added PCB specs to readme

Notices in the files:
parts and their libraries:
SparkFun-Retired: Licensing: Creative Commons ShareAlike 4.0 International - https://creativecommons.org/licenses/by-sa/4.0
